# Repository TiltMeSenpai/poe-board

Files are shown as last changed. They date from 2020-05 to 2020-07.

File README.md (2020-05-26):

# Unnamed PoE LED Driver

## Status: UNTESTED

Hub75 LED Panel driver + 10/100 Base T to MII transciever + 25W PoE supply.  
Board is untested, estimated driver logic power consumption is ~250-500ma (hopefully less).  
Remaining 4-ish amps should be enough to drive 64x64 panel at full brightness, however, with
a 1oz copper board, this will (in theory) induce a ~20C temp rise.

## Basic Stats

| Stat | Value |
|---|---|
| Voltage  | 5v  |
| Amperage | ~5A |
| Onboard current draw | TBD (Hopefully under 500ma) |
| Interface | 10/100 base T transciever, 4 debug LED's, Hub75 header |

## Board stats

| Stat | Value |
|---|---|
| Layers | 4 |
| Min Trace Width | 6 mil |
| Min Trace Spacing  | 5 mil |
| Min Drill Size | 10 mil |
| Min Via Annulus | 5 mil |
| Min Total Via Size | 20 mil |
| Blind/Buried Vias  | No |
| Impedence Control  | No |
| Copper Weight | 2 oz/Default |

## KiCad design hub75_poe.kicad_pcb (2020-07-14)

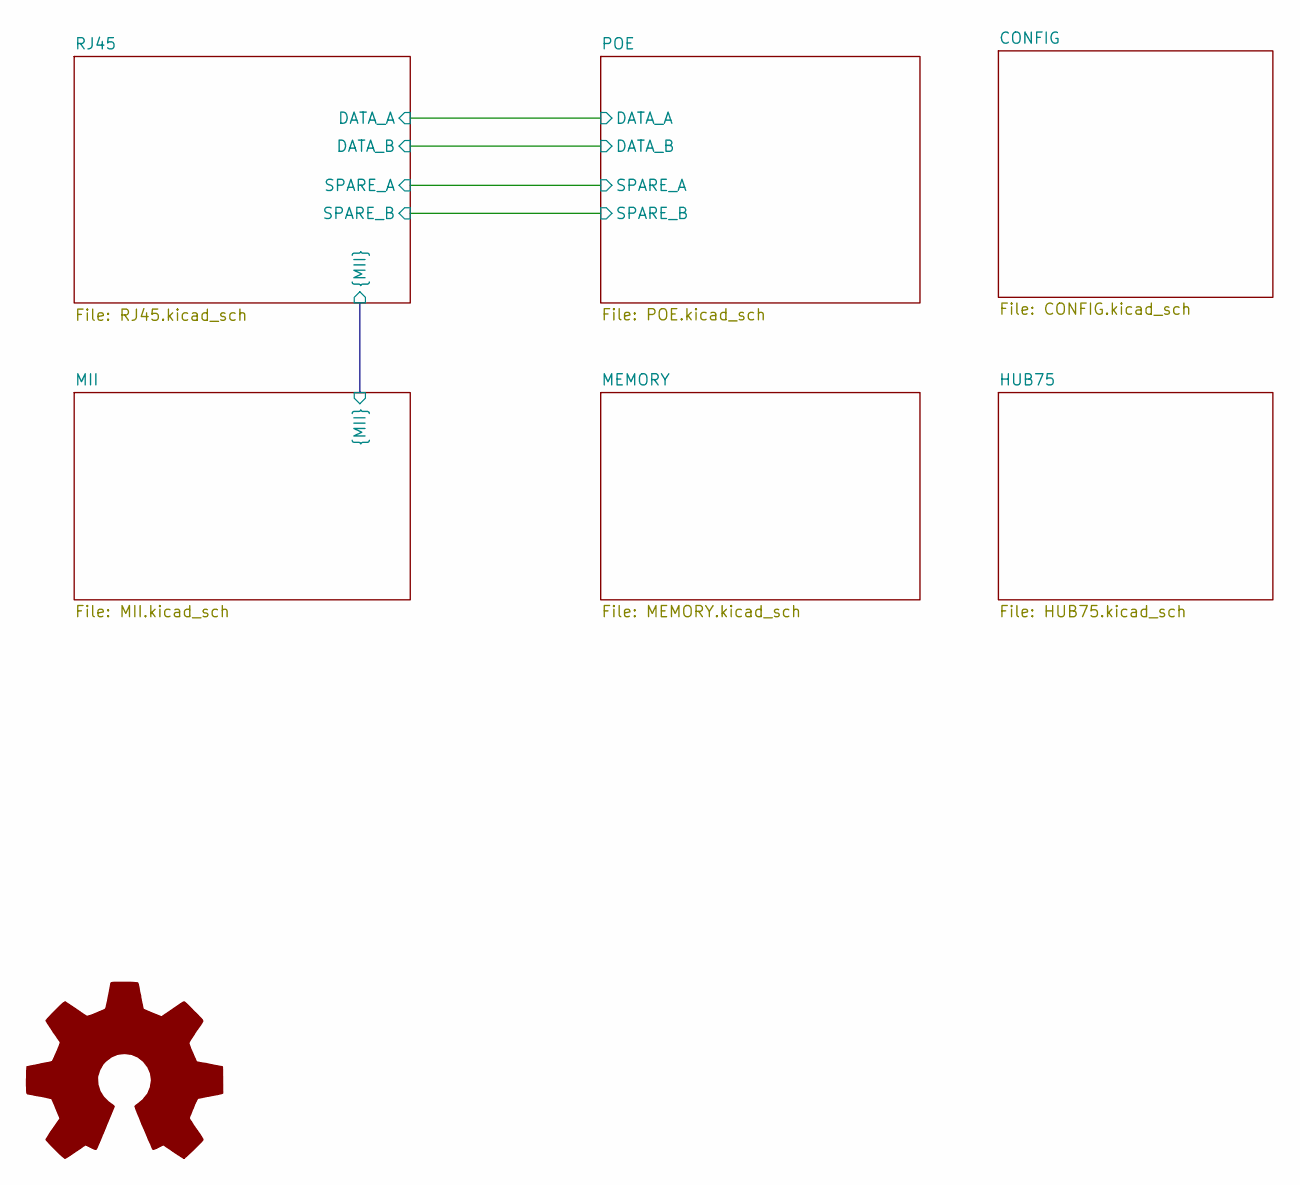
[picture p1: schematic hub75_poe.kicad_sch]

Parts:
S1: Logo_Open_Hardware_Large; OSHW-Symbol_6.7x6mm_SilkScreen

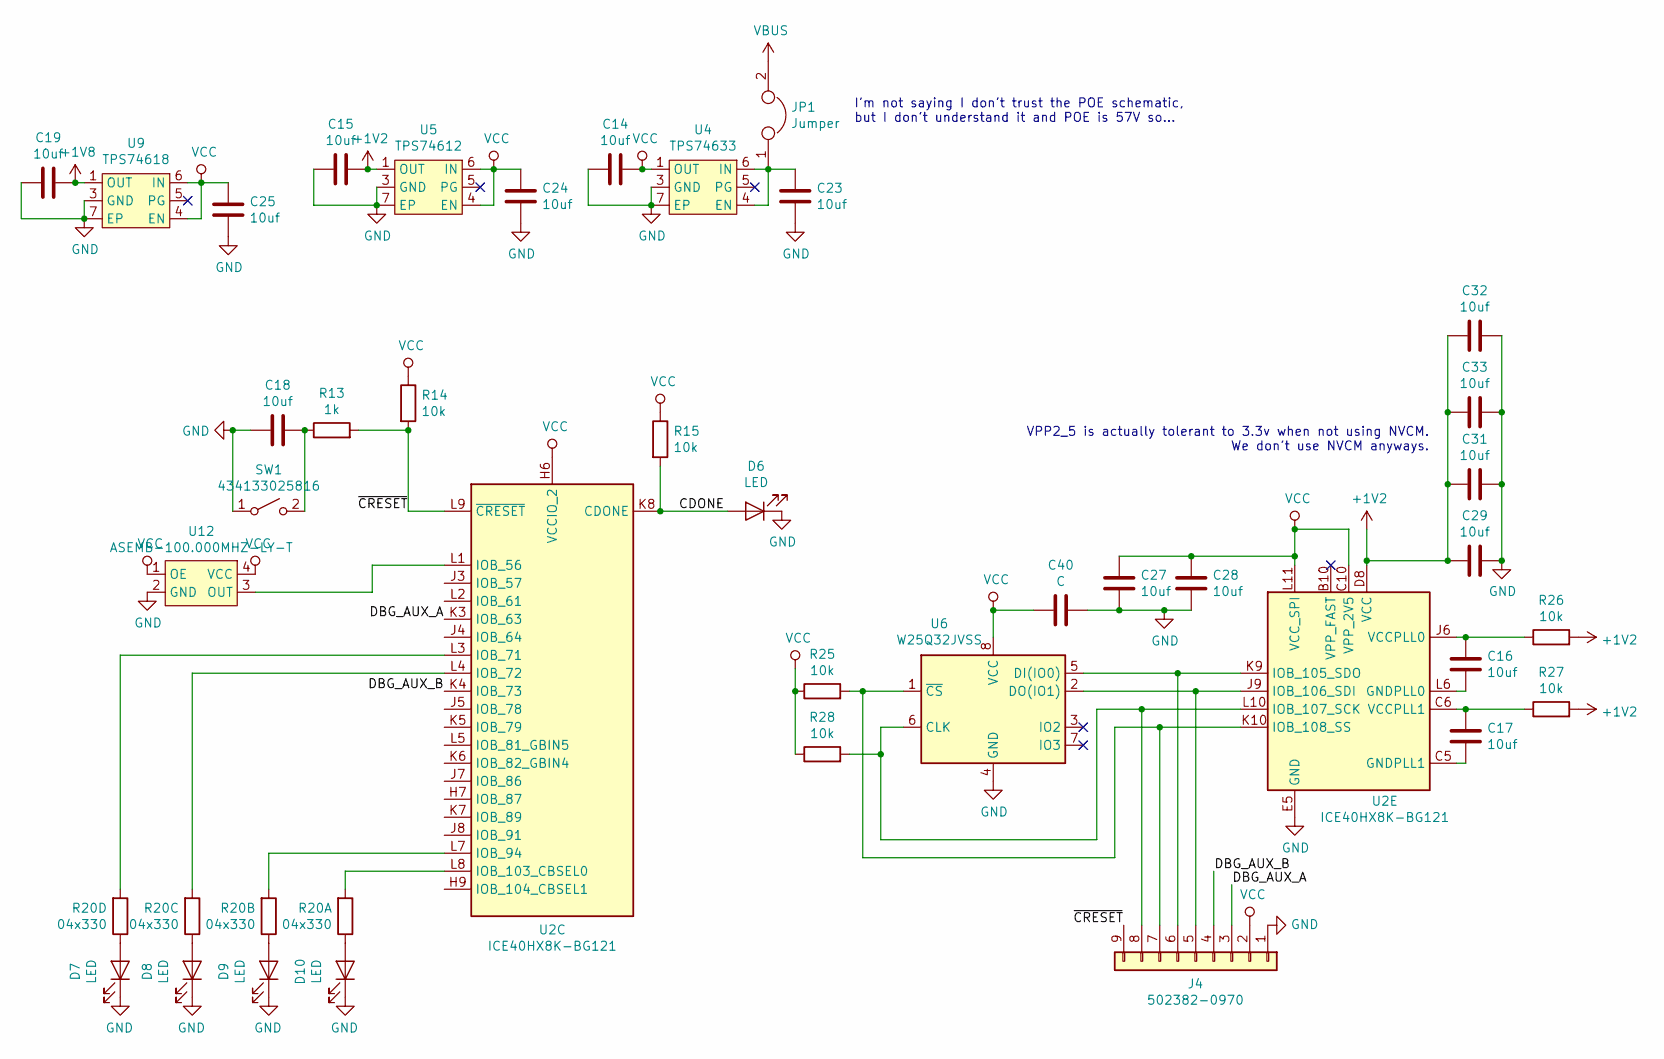
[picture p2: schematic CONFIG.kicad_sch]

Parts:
C14, C15, C16, C17, C19, C23, C24, C25, C27, C28, C29, C31, C32, C33: 10uf; C_0402_1005Metric
C18: 10uf; C_0805_2012Metric
C40: C; C_0402_1005Metric
D6, D7, D8, D9, D10: LED; D_0805_2012Metric_Castellated
J4: 502382-0970; Molex_CLIK-Mate_502382-0970_1x09-1MP_P1.25mm_Vertical
JP1: Jumper; PinSocket_1x02_P1.27mm_Vertical
R13: 1k; R_0402_1005Metric
R14, R15, R25, R26, R27, R28: 10k; R_0402_1005Metric
R20: 04x330; R_Array_Convex_4x0612
SW1: 434133025816; SW_Push_1P1T_NO_Vertical_Wuerth_434133025816
U2: ICE40HX8K-BG121; BGA-121_9.0x9.0mm_Layout11x11_P0.8mm_Ball0.4mm_Pad0.35mm_NS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
U4: TPS74633; WSON-6-1EP_2x2mm_P0.65mm_EP1x1.6mm
U5: TPS74612; WSON-6-1EP_2x2mm_P0.65mm_EP1x1.6mm
U6: W25Q32JVSS; SOIC-8_5.23x5.23mm_P1.27mm
U9: TPS74618; WSON-6-1EP_2x2mm_P0.65mm_EP1x1.6mm
U12: ASEMB-100.000MHZ-LY-T; SOIC-4

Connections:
+1V2: C15.2, C29.1, C31.1, C32.1, C33.1, R26.2, R27.2, U2.D4 (VCC), U2.D8 (VCC), U2.H4 (VCC), U2.H8 (VCC), U5.1 (OUT)
+1V8: C19.2, U9.1 (OUT); also elsewhere on the board
/CONFIG/CDONE: D6.2 (A), R15.2, U2.K8 (CDONE)
/CONFIG/DBG_AUX_A: J4.3, U2.K3 (IOB_63)
/CONFIG/DBG_AUX_B: J4.4, U2.K4 (IOB_73)
/CONFIG/~CRESET: J4.9, R13.2, R14.2, U2.L9 (~CRESET)
GND: C14.1, C15.1, C18.1, C19.1, C23.2, C24.2, C25.2, C27.1, C28.1, C29.2, C31.2, C32.2, C33.2, C40.2, D6.1 (K), D7.1 (K), D8.1 (K), D9.1 (K), D10.1 (K), J4.1, SW1.1 (A), U2.E5 (GND), U2.E6 (GND), U2.E7 (GND), U2.F5 (GND), U2.F6 (GND), U2.F7 (GND), U2.G5 (GND), U2.G6 (GND), U2.G7 (GND), U2.H5 (GND), U4.3 (GND), U4.7 (EP), U5.3 (GND), U5.7 (EP), U6.4 (GND), U9.3 (GND), U9.7 (EP), U12.2 (GND); also elsewhere on the board
unnamed: C16.1, R26.1, U2.J6 (VCCPLL0)
unnamed: C16.2, U2.L6 (GNDPLL0)
unnamed: C17.1, R27.1, U2.C6 (VCCPLL1)
unnamed: C17.2, U2.C5 (GNDPLL1)
unnamed: C18.2, R13.1, SW1.2 (B)
unnamed: C23.1, JP1.1, U4.4 (EN), U4.6 (IN)
unnamed: D7.2 (A), R20.5
unnamed: D8.2 (A), R20.6
unnamed: D9.2 (A), R20.7
unnamed: D10.2 (A), R20.8
unnamed: J4.5, U2.J9 (IOB_106_SDI), U6.2 (DO(IO1))
unnamed: J4.6, U2.K9 (IOB_105_SDO), U6.5 (DI(IO0))
unnamed: J4.7, R25.2, U2.K10 (IOB_108_SS), U6.1 (~CS)
unnamed: J4.8, R28.2, U2.L10 (IOB_107_SCK), U6.6 (CLK)
unnamed: R20.1, U2.L8 (IOB_103_CBSEL0)
unnamed: R20.2, U2.L7 (IOB_94)
unnamed: R20.3, U2.L4 (IOB_72)
unnamed: R20.4, U2.L3 (IOB_71)
unnamed: U2.L1 (IOB_56), U12.3 (OUT)
VBUS: JP1.2; also elsewhere on the board
VCC: C14.2, C24.1, C25.1, C27.2, C28.2, C40.1, J4.2, R14.1, R15.1, R25.1, R28.1, U2.C10 (VPP_2V5), U2.H6 (VCCIO_2), U2.L11 (VCC_SPI), U4.1 (OUT), U5.4 (EN), U5.6 (IN), U6.8 (VCC), U9.4 (EN), U9.6 (IN), U12.1 (OE), U12.4 (VCC); also elsewhere on the board

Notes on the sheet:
I'm not saying I don't trust the POE schematic, but I don't understand it and POE is 57V so...
VPP2_5 is actually tolerant to 3.3v when not using NVCM. We don't use NVCM anyways.

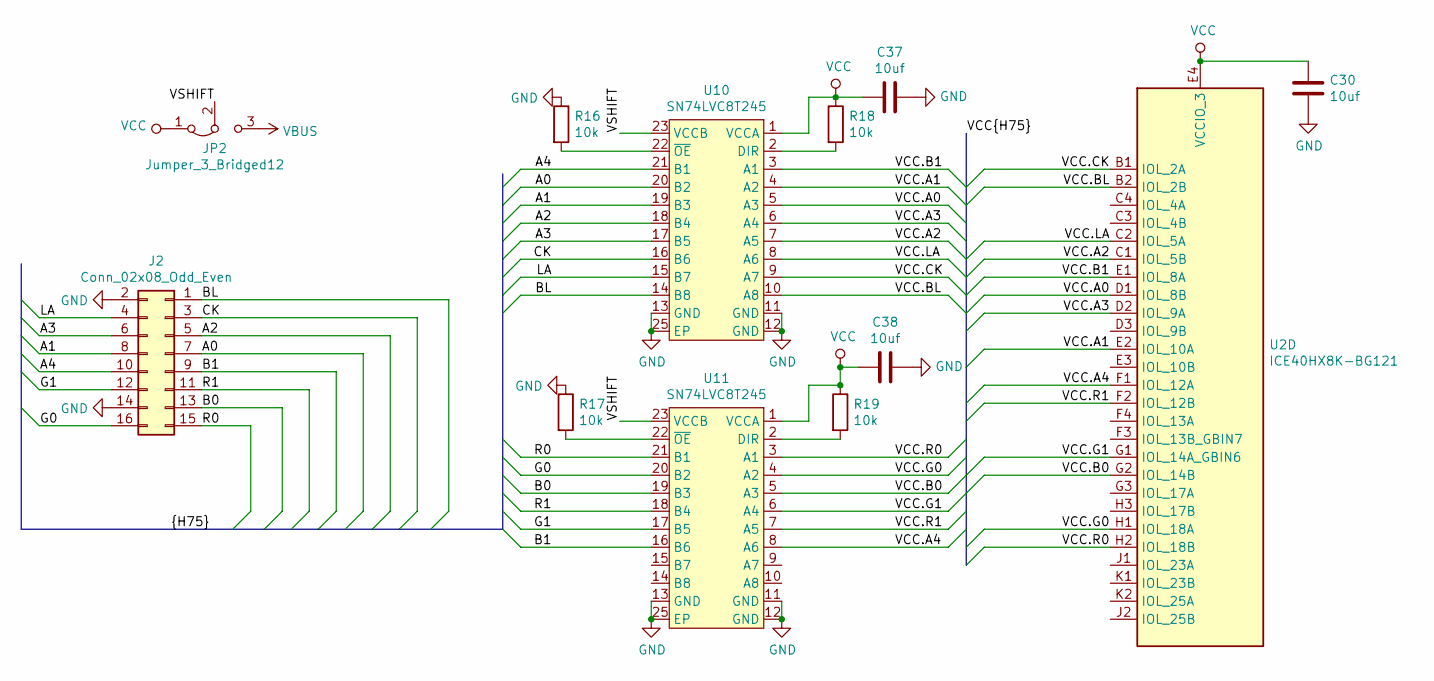
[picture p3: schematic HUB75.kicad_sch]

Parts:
C30, C37, C38: 10uf; C_0402_1005Metric
J2: Conn_02x08_Odd_Even; PinSocket_2x08_P2.54mm_Vertical
JP2: Jumper_3_Bridged12; PinHeader_1x03_P1.27mm_Vertical
R16, R17, R18, R19: 10k; R_0402_1005Metric
U2: ICE40HX8K-BG121; BGA-121_9.0x9.0mm_Layout11x11_P0.8mm_Ball0.4mm_Pad0.35mm_NS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
U10, U11: SN74LVC8T245

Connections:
/HUB75/A0: J2.7, U10.20 (B2)
/HUB75/A1: J2.8, U10.19 (B3)
/HUB75/A2: J2.5, U10.18 (B4)
/HUB75/A3: J2.6, U10.17 (B5)
/HUB75/A4: J2.10, U10.21 (B1)
/HUB75/B0: J2.13, U11.19 (B3)
/HUB75/B1: J2.9, U11.16 (B6)
/HUB75/BL: J2.1, U10.14 (B8)
/HUB75/CK: J2.3, U10.16 (B6)
/HUB75/G0: J2.16, U11.20 (B2)
/HUB75/G1: J2.12, U11.17 (B5)
/HUB75/LA: J2.4, U10.15 (B7)
/HUB75/R0: J2.15, U11.21 (B1)
/HUB75/R1: J2.11, U11.18 (B4)
/HUB75/VCC.A0: U2.D1 (IOL_8B), U10.5 (A3)
/HUB75/VCC.A1: U2.E2 (IOL_10A), U10.4 (A2)
/HUB75/VCC.A2: U2.C1 (IOL_5B), U10.7 (A5)
/HUB75/VCC.A3: U2.D2 (IOL_9A), U10.6 (A4)
/HUB75/VCC.A4: U2.F1 (IOL_12A), U11.8 (A6)
/HUB75/VCC.B0: U2.G2 (IOL_14B), U11.5 (A3)
/HUB75/VCC.B1: U2.E1 (IOL_8A), U10.3 (A1)
/HUB75/VCC.BL: U2.B2 (IOL_2B), U10.10 (A8)
/HUB75/VCC.CK: U2.B1 (IOL_2A), U10.9 (A7)
/HUB75/VCC.G0: U2.H1 (IOL_18A), U11.4 (A2)
/HUB75/VCC.G1: U2.G1 (IOL_14A_GBIN6), U11.6 (A4)
/HUB75/VCC.LA: U2.C2 (IOL_5A), U10.8 (A6)
/HUB75/VCC.R0: U2.H2 (IOL_18B), U11.3 (A1)
/HUB75/VCC.R1: U2.F2 (IOL_12B), U11.7 (A5)
/HUB75/VSHIFT: JP2.2 (C), U10.23 (VCCB), U10.24 (VCCB), U11.23 (VCCB), U11.24 (VCCB)
GND: C30.2, C37.2, C38.2, J2.2, J2.14, R16.1, R17.1, U10.11 (GND), U10.12 (GND), U10.13 (GND), U10.25 (EP), U11.11 (GND), U11.12 (GND), U11.13 (GND), U11.25 (EP); also elsewhere on the board
unnamed: R16.2, U10.22 (~OE)
unnamed: R17.2, U11.22 (~OE)
unnamed: R18.2, U10.2 (DIR)
unnamed: R19.2, U11.2 (DIR)
VBUS: JP2.3 (B); also elsewhere on the board
VCC: C30.1, C37.1, C38.1, JP2.1 (A), R18.1, R19.1, U2.E4 (VCCIO_3), U2.G4 (VCCIO_3), U10.1 (VCCA), U11.1 (VCCA); also elsewhere on the board

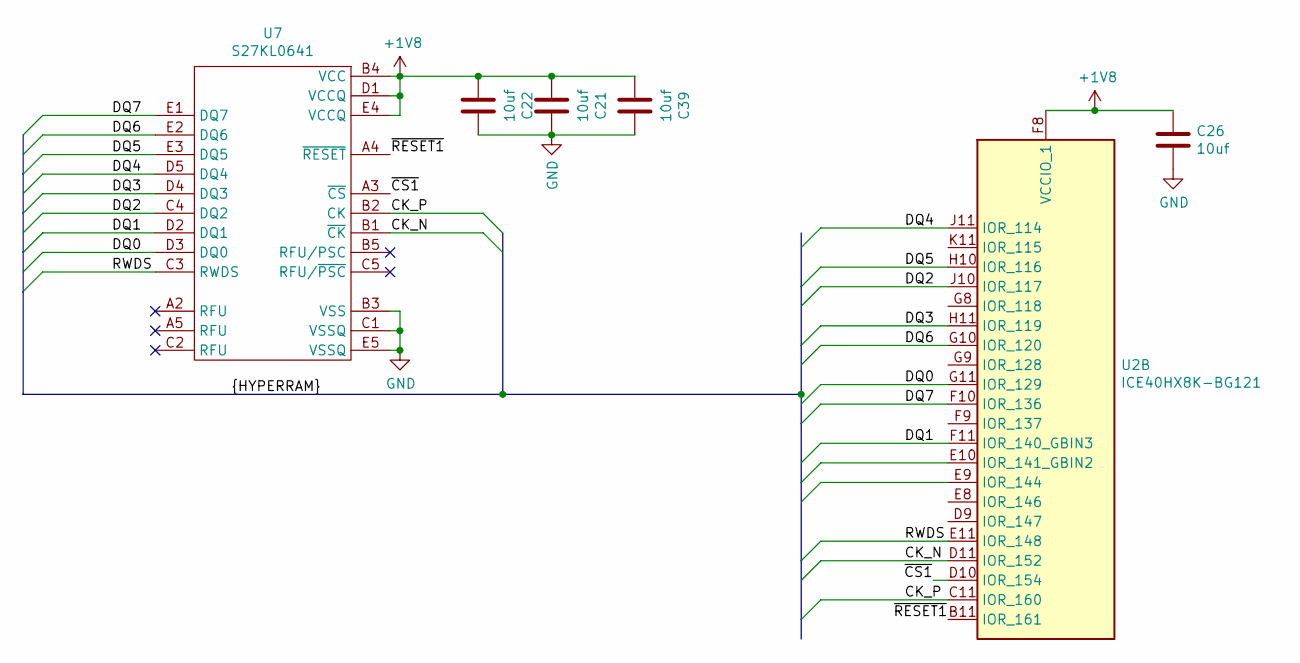
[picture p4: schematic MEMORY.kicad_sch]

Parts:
C21, C22, C26, C39: 10uf; C_0402_1005Metric
U2: ICE40HX8K-BG121; BGA-121_9.0x9.0mm_Layout11x11_P0.8mm_Ball0.4mm_Pad0.35mm_NS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
U7: S27KL0641; BGA-24_5x5_6.0x8.0mm

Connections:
+1V8: C21.1, C22.1, C26.1, C39.1, U2.F8 (VCCIO_1), U7.B4 (VCC), U7.D1 (VCCQ), U7.E4 (VCCQ); also elsewhere on the board
/MEMORY/CK_N: U2.D11 (IOR_152), U7.B1 (~CK)
/MEMORY/CK_P: U2.C11 (IOR_160), U7.B2 (CK)
/MEMORY/DQ0: U2.G11 (IOR_129), U7.D3 (DQ0)
/MEMORY/DQ1: U2.F11 (IOR_140_GBIN3), U7.D2 (DQ1)
/MEMORY/DQ2: U2.J10 (IOR_117), U7.C4 (DQ2)
/MEMORY/DQ3: U2.H11 (IOR_119), U7.D4 (DQ3)
/MEMORY/DQ4: U2.J11 (IOR_114), U7.D5 (DQ4)
/MEMORY/DQ5: U2.H10 (IOR_116), U7.E3 (DQ5)
/MEMORY/DQ6: U2.G10 (IOR_120), U7.E2 (DQ6)
/MEMORY/DQ7: U2.F10 (IOR_136), U7.E1 (DQ7)
/MEMORY/RWDS: U2.E11 (IOR_148), U7.C3 (RWDS)
/MEMORY/~CS1: U2.D10 (IOR_154), U7.A3 (~CS)
/MEMORY/~RESET1: U2.B11 (IOR_161), U7.A4 (~RESET)
GND: C21.2, C22.2, C26.2, C39.2, U7.B3 (VSS), U7.C1 (VSSQ), U7.E5 (VSSQ); also elsewhere on the board

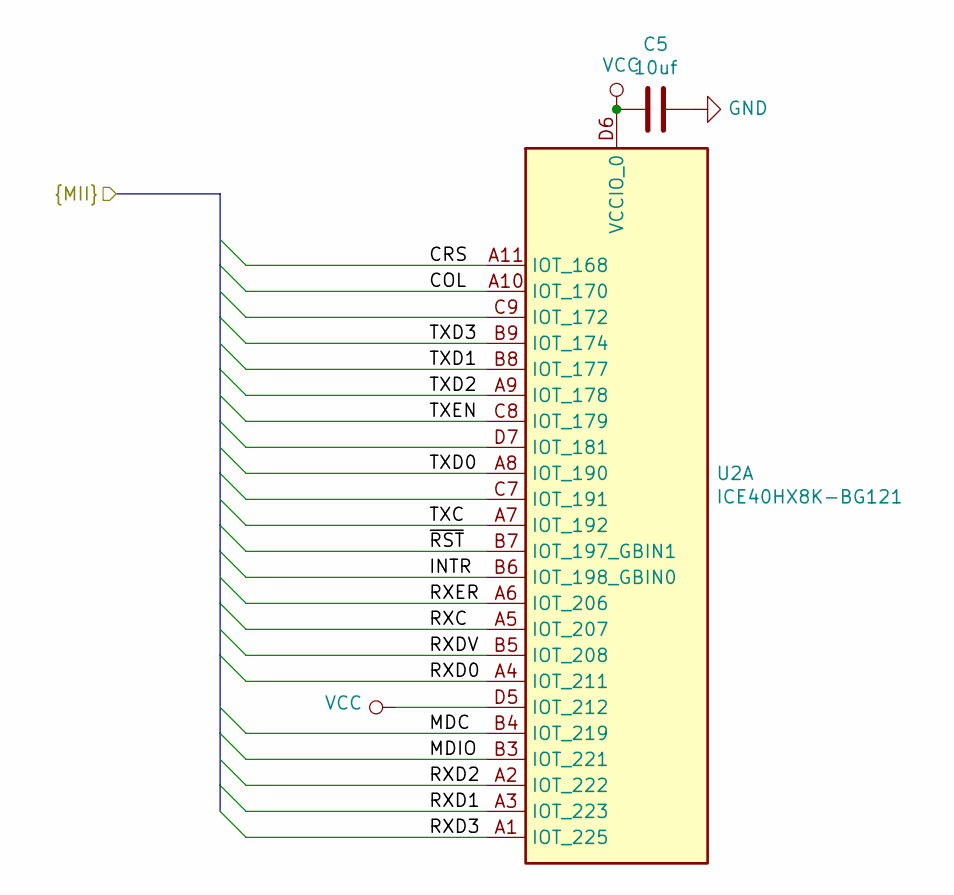
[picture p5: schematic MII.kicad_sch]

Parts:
C5: 10uf; C_0402_1005Metric
U2: ICE40HX8K-BG121; BGA-121_9.0x9.0mm_Layout11x11_P0.8mm_Ball0.4mm_Pad0.35mm_NS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

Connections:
/COL: U2.A10 (IOT_170); also elsewhere on the board
/CRS: U2.A11 (IOT_168); also elsewhere on the board
/INTR: U2.B6 (IOT_198_GBIN0); also elsewhere on the board
/MDC: U2.B4 (IOT_219); also elsewhere on the board
/MDIO: U2.B3 (IOT_221); also elsewhere on the board
/RXC: U2.A5 (IOT_207); also elsewhere on the board
/RXD0: U2.A4 (IOT_211); also elsewhere on the board
/RXD1: U2.A3 (IOT_223); also elsewhere on the board
/RXD2: U2.A2 (IOT_222); also elsewhere on the board
/RXD3: U2.A1 (IOT_225); also elsewhere on the board
/RXDV: U2.B5 (IOT_208); also elsewhere on the board
/RXER: U2.A6 (IOT_206); also elsewhere on the board
/TXC: U2.A7 (IOT_192); also elsewhere on the board
/TXD0: U2.A8 (IOT_190); also elsewhere on the board
/TXD1: U2.B8 (IOT_177); also elsewhere on the board
/TXD2: U2.A9 (IOT_178); also elsewhere on the board
/TXD3: U2.B9 (IOT_174); also elsewhere on the board
/TXEN: U2.C8 (IOT_179); also elsewhere on the board
/~RST: U2.B7 (IOT_197_GBIN1); also elsewhere on the board
GND: C5.2; also elsewhere on the board
VCC: C5.1, U2.D5 (IOT_212), U2.D6 (VCCIO_0); also elsewhere on the board

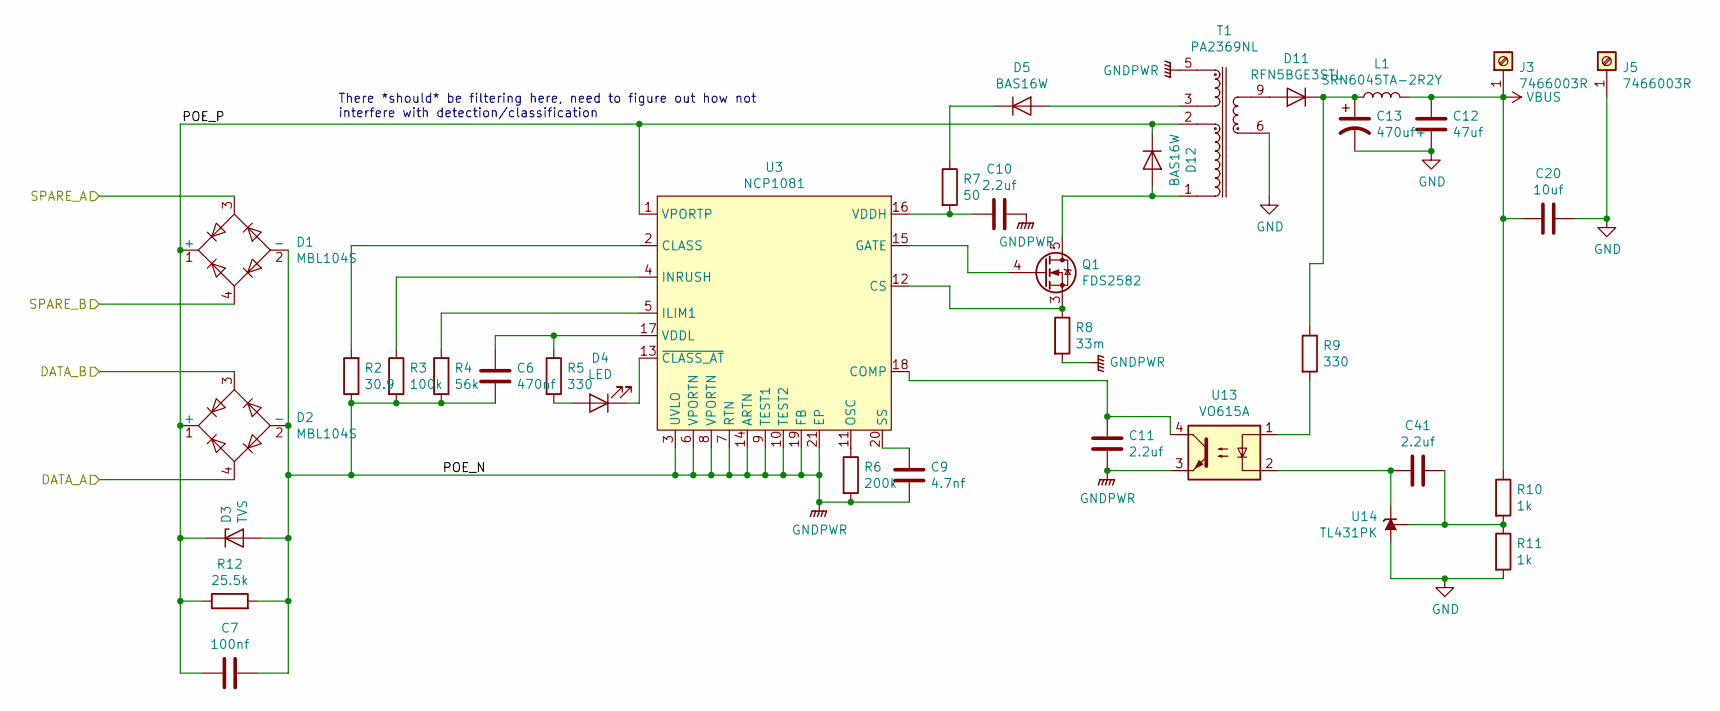
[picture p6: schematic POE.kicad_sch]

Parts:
C6: 470nf; C_0402_1005Metric
C7: 100nf; C_0805_2012Metric
C9: 4.7nf; C_0402_1005Metric
C10, C11, C41: 2.2uf; C_0402_1005Metric
C12: 47uf; C_0805_2012Metric
C13: 470uf+; CP_Elec_8x10
C20: 10uf; C_0805_2012Metric
D1, D2: MBL104S; Diode_Bridge_Vishay_MBLS
D3: TVS; D_SMA
D4: LED; D_0805_2012Metric_Castellated
D5, D12: BAS16W; SOT-323_SC-70
D11: RFN5BGE3STL; TO-252-2
J3, J5: 7466003R
L1: SRN6045TA-2R2Y; L_Bourns_SRN6045TA
Q1: FDS2582; SOP-8_3.9x4.9mm_P1.27mm
R2: 30.9; R_0402_1005Metric
R3: 100k; R_0402_1005Metric
R4: 56k; R_0402_1005Metric
R5, R9: 330; R_0402_1005Metric
R6: 200k; R_0402_1005Metric
R7: 50; R_0402_1005Metric
R8: 33m; R_2512_6332Metric
R10, R11: 1k; R_0402_1005Metric
R12: 25.5k; R_0805_2012Metric
T1: PA2369NL
U3: NCP1081; HTSSOP-20-1EP_4.4x6.5mm_P0.65mm_EP3.4x6.5mm
U13: VO615A; VO615A-9X017T
U14: TL431PK; SOT-89-3

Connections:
/DATA_A: D2.4 (~~); also elsewhere on the board
/DATA_B: D2.3 (~~); also elsewhere on the board
/POE/POE_P: C7.1, D1.1 (+), D2.1 (+), D3.1 (A1), D12.3 (K), R12.1, T1.2, U3.1 (VPORTP)
/SPARE_A: D1.3 (~~); also elsewhere on the board
/SPARE_B: D1.4 (~~); also elsewhere on the board
GND: C12.2, C13.2, C20.2, J5.1, R11.2, T1.6, T1.7, U14.2 (A); also elsewhere on the board
GNDPWR: C6.2, C7.2, C9.2, C10.2, C11.2, D1.2 (-), D2.2 (-), D3.2 (A2), R2.1, R3.2, R4.1, R6.2, R8.2, R12.2, T1.5, U3.3 (UVLO), U3.6 (VPORTN), U3.7 (RTN), U3.8 (VPORTN), U3.9 (TEST1), U3.10 (TEST2), U3.14 (ARTN), U3.19 (FB), U3.21 (EP), U13.3; also elsewhere on the board
unnamed: C6.1, R5.1, U3.17 (VDDL)
unnamed: C9.1, U3.20 (SS)
unnamed: C10.1, R7.2, U3.16 (VDDH)
unnamed: C11.1, U3.18 (COMP), U13.4
unnamed: C13.1, D11.2 (K), L1.1, R9.1
unnamed: C41.1, U13.2, U14.3 (K)
unnamed: C41.2, R10.2, R11.1, U14.1 (REF)
unnamed: D4.1 (K), U3.13 (~CLASS_AT)
unnamed: D4.2 (A), R5.2
unnamed: D5.1 (A), T1.3
unnamed: D5.3 (K), R7.1
unnamed: D11.1 (A), D11.3 (A), T1.9, T1.10
unnamed: D12.1 (A), Q1.5 (D), Q1.6 (D), Q1.7 (D), Q1.8 (D), T1.1
unnamed: Q1.1 (S), Q1.2 (S), Q1.3 (S), R8.1, U3.12 (CS)
unnamed: Q1.4 (G), U3.15 (GATE)
unnamed: R2.2, U3.2 (CLASS)
unnamed: R3.1, U3.4 (INRUSH)
unnamed: R4.2, U3.5 (ILIM1)
unnamed: R6.1, U3.11 (OSC)
unnamed: R9.2, U13.1
VBUS: C12.1, C20.1, J3.1, L1.2, R10.1; also elsewhere on the board

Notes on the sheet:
There *should* be filtering here, need to figure out how not interfere with detection/classification

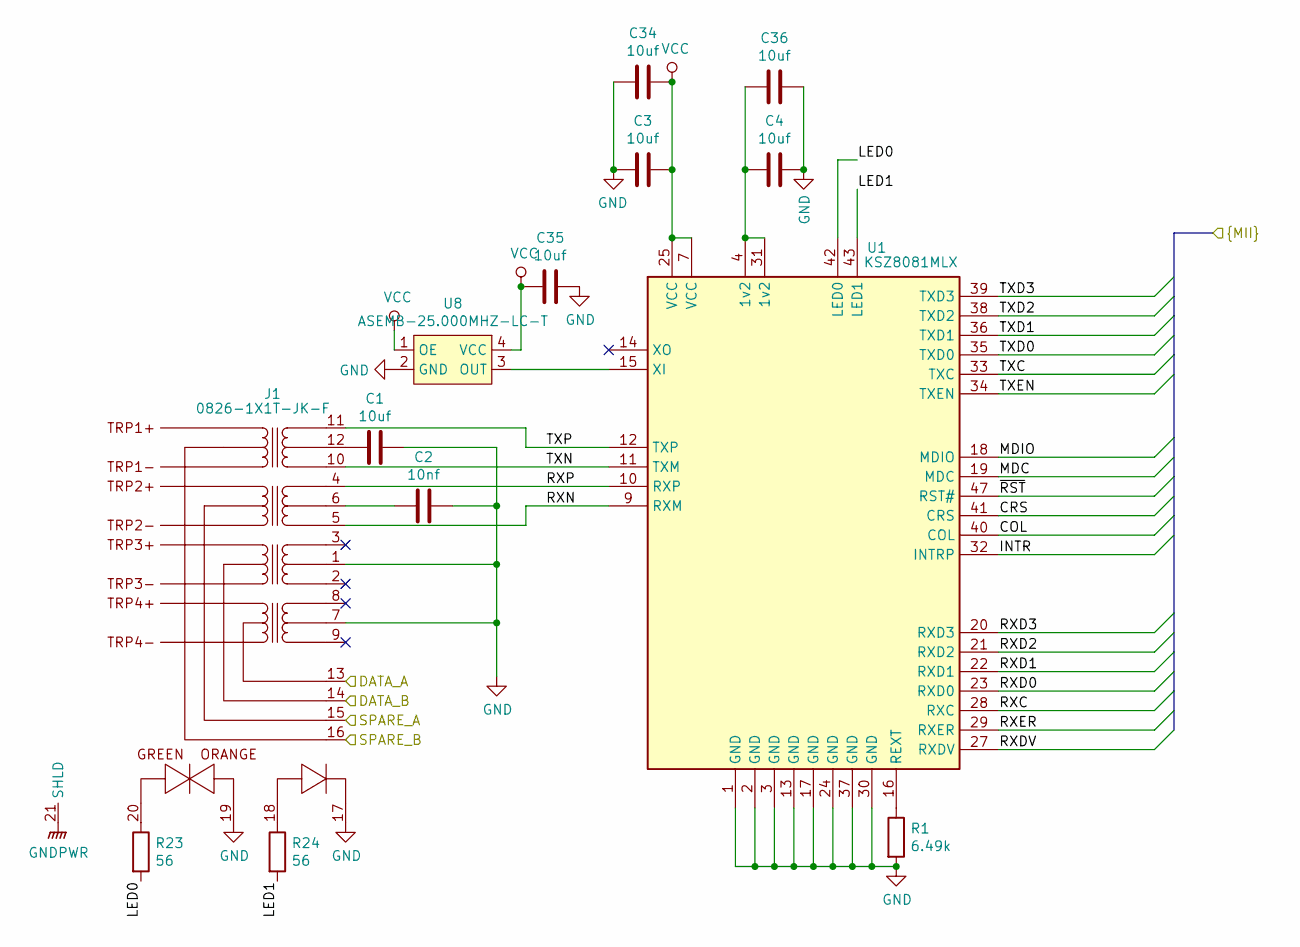
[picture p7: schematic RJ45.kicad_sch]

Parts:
C1: 10uf; C_0805_2012Metric
C2: 10nf; C_0805_2012Metric
C3, C4, C34, C35, C36: 10uf; C_0402_1005Metric
J1: 0826-1X1T-JK-F; 08261X1TGHF
R1: 6.49k; R_0402_1005Metric
R23, R24: 56; R_0402_1005Metric
U1: KSZ8081MLX; LQFP-48_7x7mm_P0.5mm
U8: ASEMB-25.000MHZ-LC-T; SOIC-4

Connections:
/COL: U1.40 (COL); also elsewhere on the board
/CRS: U1.41 (CRS); also elsewhere on the board
/DATA_A: J1.13; also elsewhere on the board
/DATA_B: J1.14; also elsewhere on the board
/INTR: U1.32 (INTRP); also elsewhere on the board
/MDC: U1.19 (MDC); also elsewhere on the board
/MDIO: U1.18 (MDIO); also elsewhere on the board
/RJ45/LED0: R23.2, U1.42 (LED0)
/RJ45/LED1: R24.2, U1.43 (LED1)
/RJ45/RXN: J1.5, U1.9 (RXM)
/RJ45/RXP: J1.4, U1.10 (RXP)
/RJ45/TXN: J1.10, U1.11 (TXM)
/RJ45/TXP: J1.11, U1.12 (TXP)
/RXC: U1.28 (RXC); also elsewhere on the board
/RXD0: U1.23 (RXD0); also elsewhere on the board
/RXD1: U1.22 (RXD1); also elsewhere on the board
/RXD2: U1.21 (RXD2); also elsewhere on the board
/RXD3: U1.20 (RXD3); also elsewhere on the board
/RXDV: U1.27 (RXDV); also elsewhere on the board
/RXER: U1.29 (RXER); also elsewhere on the board
/SPARE_A: J1.15; also elsewhere on the board
/SPARE_B: J1.16; also elsewhere on the board
/TXC: U1.33 (TXC); also elsewhere on the board
/TXD0: U1.35 (TXD0); also elsewhere on the board
/TXD1: U1.36 (TXD1); also elsewhere on the board
/TXD2: U1.38 (TXD2); also elsewhere on the board
/TXD3: U1.39 (TXD3); also elsewhere on the board
/TXEN: U1.34 (TXEN); also elsewhere on the board
/~RST: U1.47 (RST#); also elsewhere on the board
GND: C1.2, C2.2, C3.2, C4.2, C34.2, C35.2, C36.2, J1.1, J1.7, J1.17, J1.19, R1.2, U1.1 (GND), U1.2 (GND), U1.3 (GND), U1.13 (GND), U1.17 (GND), U1.24 (GND), U1.30 (GND), U1.37 (GND), U8.2 (GND); also elsewhere on the board
GNDPWR: J1.21 (SHLD), J1.22 (SHLD); also elsewhere on the board
unnamed: C1.1, J1.12
unnamed: C2.1, J1.6
unnamed: C4.1, C36.1, U1.4 (1v2), U1.31 (1v2)
unnamed: J1.18, R24.1
unnamed: J1.20, R23.1
unnamed: R1.1, U1.16 (REXT)
unnamed: U1.15 (XI), U8.3 (OUT)
VCC: C3.1, C34.1, C35.1, U1.7 (VCC), U1.25 (VCC), U8.1 (OE), U8.4 (VCC); also elsewhere on the board

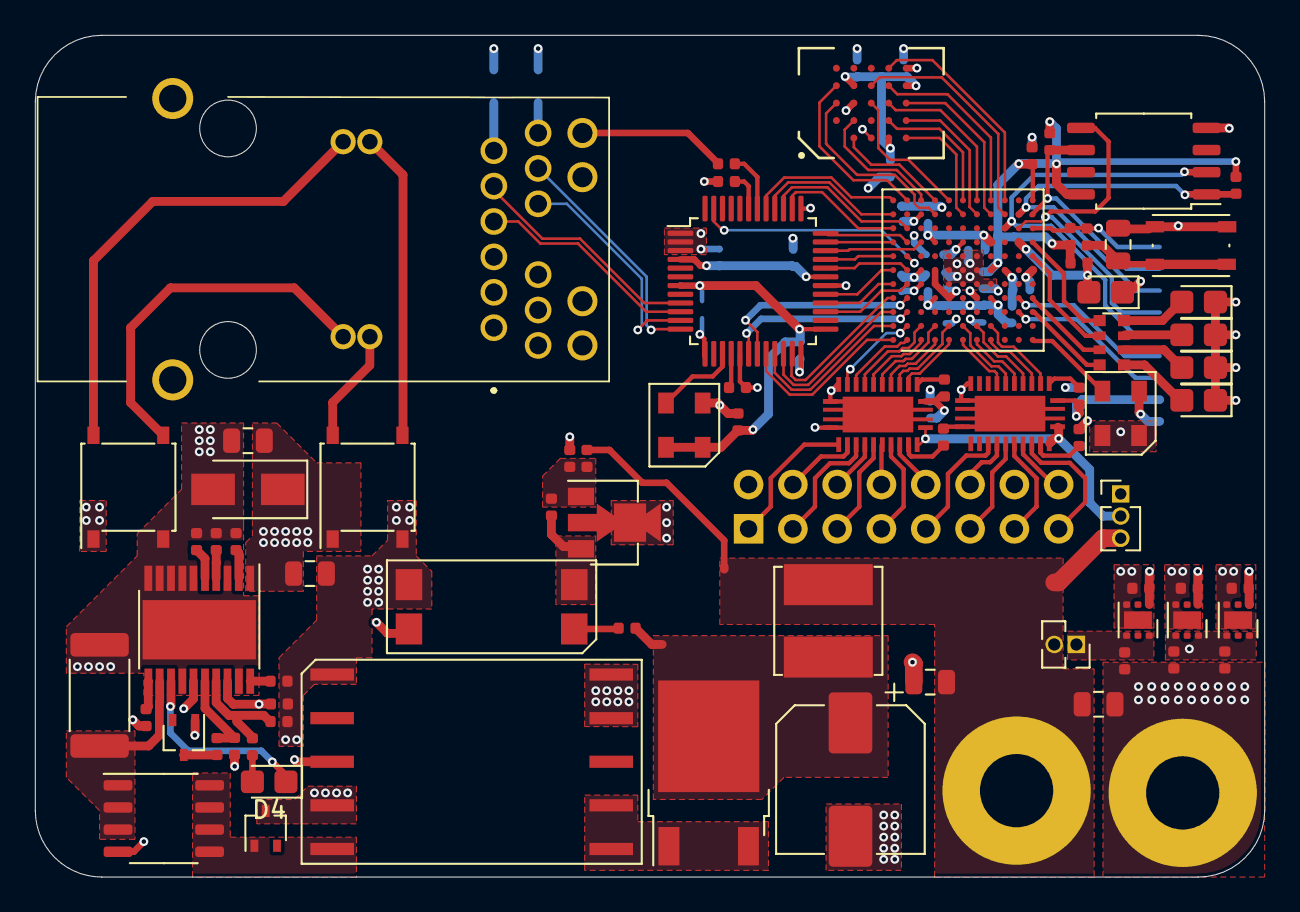
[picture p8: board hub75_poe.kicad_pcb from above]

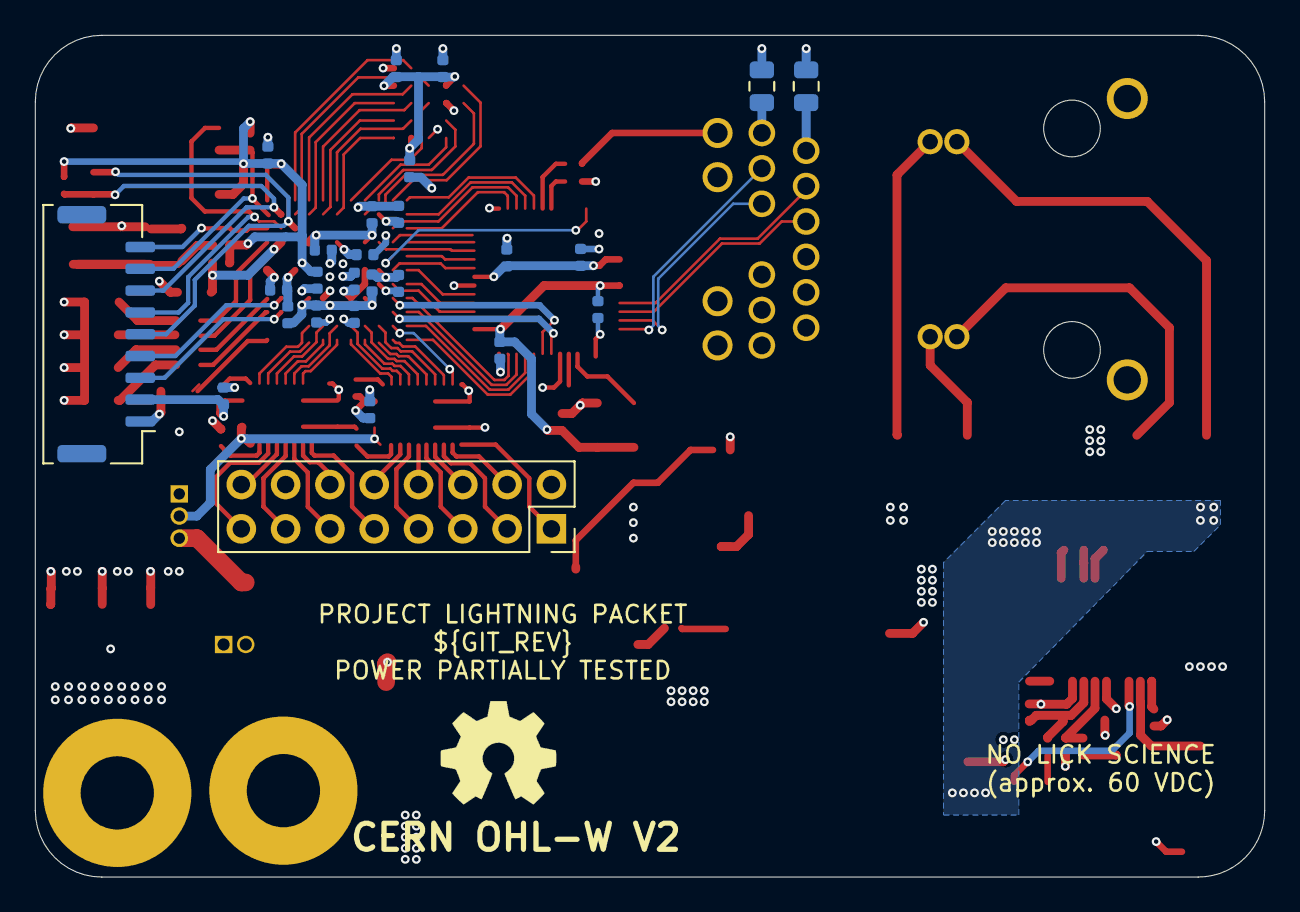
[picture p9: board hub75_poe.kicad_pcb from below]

Board: 4 copper layers, 70.5 x 48.3 mm, 104 parts (27 on the bottom side), 132 nets.

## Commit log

2020-06-02 Routing changes, pullups, etc
    [CONFIG.kicad_sch, HUB75.kicad_sch, MEMORY.kicad_sch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]
2020-06-03 Routing cleanup, fix primary transformer
    [CONFIG.kicad_sch, HUB75.kicad_sch, MEMORY.kicad_sch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]
2020-06-12 Change PoE controller to NCP1081
    [CONFIG.kicad_sch, HUB75.kicad_sch, MEMORY.kicad_sch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]
2020-06-14 Update routing and icons/text
    [CONFIG.kicad_sch, HUB75.kicad_sch, MEMORY.kicad_sch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]
2020-06-15 Add missing detection resistor
    [CONFIG.kicad_sch, HUB75.kicad_sch, MEMORY.kicad_sch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]
2020-06-25 More routing cleanup
    [CONFIG.kicad_sch, HUB75.kicad_sch, MEMORY.kicad_sch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]
2020-06-26 Fix SOT-89-3 footprint
    [CONFIG.kicad_sch, HUB75.kicad_sch, MEMORY.kicad_sch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]
2020-06-26 Change gerber plot invocation
2020-07-02 Swap low voltage caps, remove hv side LC filter
    [CONFIG.kicad_sch, HUB75.kicad_sch, MEMORY.kicad_sch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]
2020-07-02 Add transformer snubber diode
    [POE.kicad_sch, hub75_poe.kicad_pcb, hub75_poe.kicad_sch]
2020-07-05 Move snubber diode to board front
    [hub75_poe.kicad_pcb]
2020-07-14 Add @dev ref to plot-gerbers step
    [hub75_poe.kicad_pcb]

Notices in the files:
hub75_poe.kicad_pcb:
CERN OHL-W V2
